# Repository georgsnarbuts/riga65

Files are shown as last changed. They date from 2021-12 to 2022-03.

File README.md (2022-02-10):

# riga65

<br />This work is licensed under a <a rel="license" href="http://creativecommons.org/licenses/by-nc/4.0/">Creative Commons Attribution-NonCommercial 4.0 International License</a>.  

a 65 % keyboard

A custom 65% mechanical keyboard with 100% through hole component assembly.  
Running atMega 32a MCU.  
Featuring a 128x32 oled display and an optional rotary encoder. Running QMK.    
  
Sample board built with gateron yellow switches (filmed and lubed with krytox 205 grade 0) and durock stabilizers.  

IMG_1587 2-min
  






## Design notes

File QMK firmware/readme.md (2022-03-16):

# riga65

*A short description of the keyboard/project*

* Keyboard Maintainer: [Georgs Narbuts](https://github.com/georgsnarbuts)
* Hardware Supported: Riga65 pcb, atmega32a mcu.

Make example for this keyboard (after setting up your build environment):

    make riga65:default

Flashing example for this keyboard:

    make riga65:default:flash

See the [build environment setup](https://docs.qmk.fm/#/getting_started_build_tools) and the [make instructions](https://docs.qmk.fm/#/getting_started_make_guide) for more information. Brand new to QMK? Start with our [Complete Newbs Guide](https://docs.qmk.fm/#/newbs).

## Bootloader

Enter the bootloader in 3 ways:

* **Bootmagic reset**: Hold down the key at (0,0) in the matrix (usually the top left key or Escape) and plug in the keyboard
* **Physical reset button**: Briefly press the button on the back of the PCB - some may have pads you must short instead
* **Keycode in layout**: Press the key mapped to `RESET` if it is available

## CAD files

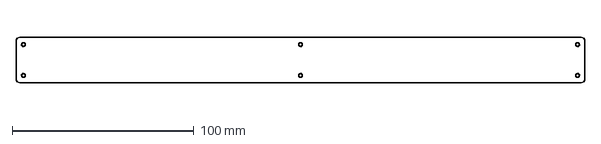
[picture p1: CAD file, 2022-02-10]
ACRYLIC GUARD/Untitled.dxf
313.0 x 25.0 mm

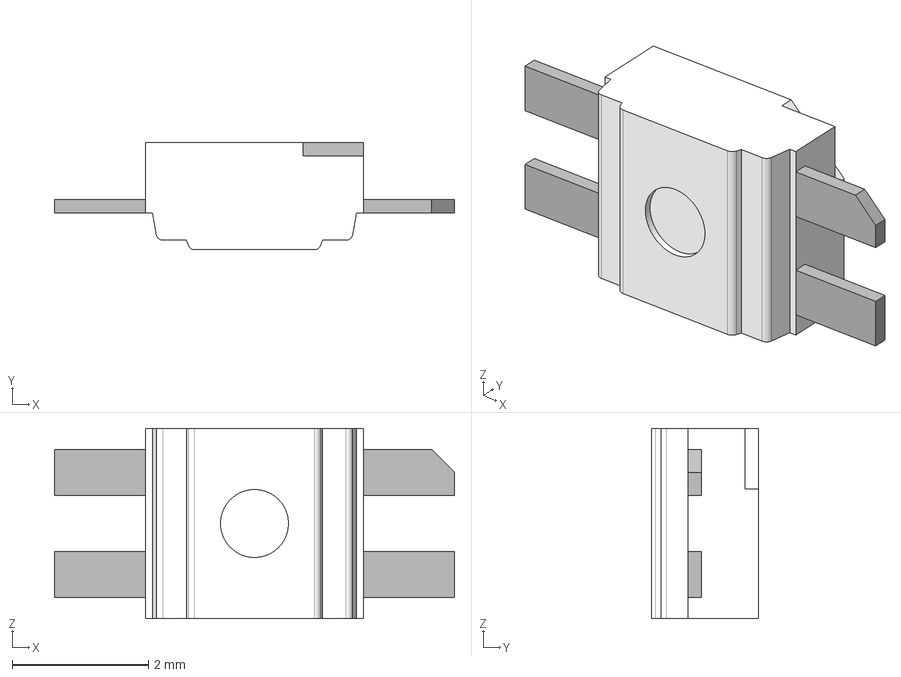
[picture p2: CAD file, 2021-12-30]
PCB/Keebio-Parts.pretty-master/3dmodels/SK6812MINI-E v1.step
5.88 x 1.58 x 2.80 mm

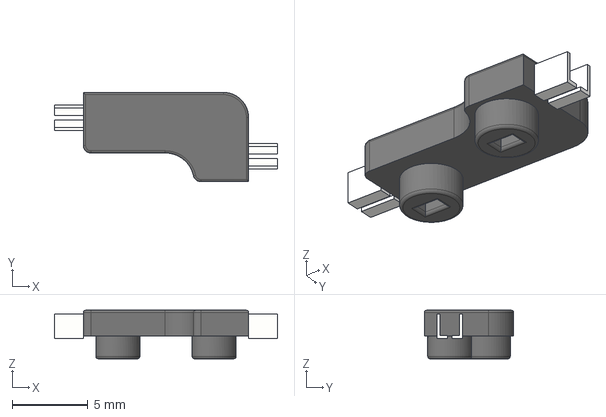
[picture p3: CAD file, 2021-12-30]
PCB/keyboard_parts.pretty-master/keyboard_parts.pretty-master/3D/Kailh_Socket.step
14.7 x 5.89 x 3.20 mm

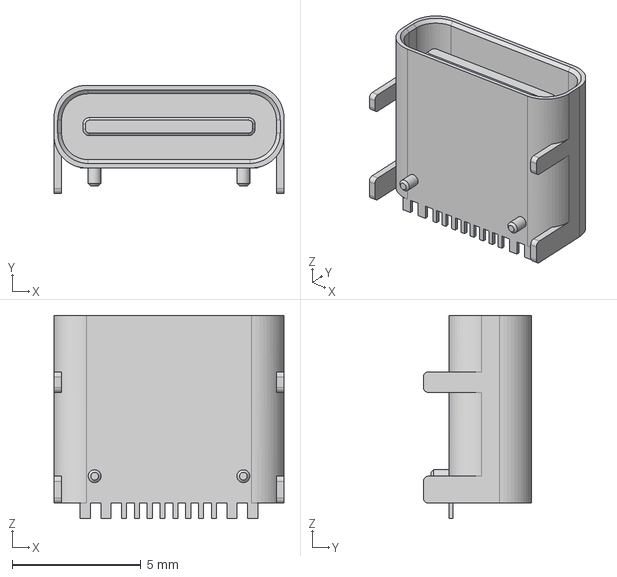
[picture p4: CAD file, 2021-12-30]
PCB/Keebio-Parts.pretty-master/3dmodels/HRO TYPE-C-31-M-12.step
8.94 x 4.21 x 7.90 mm

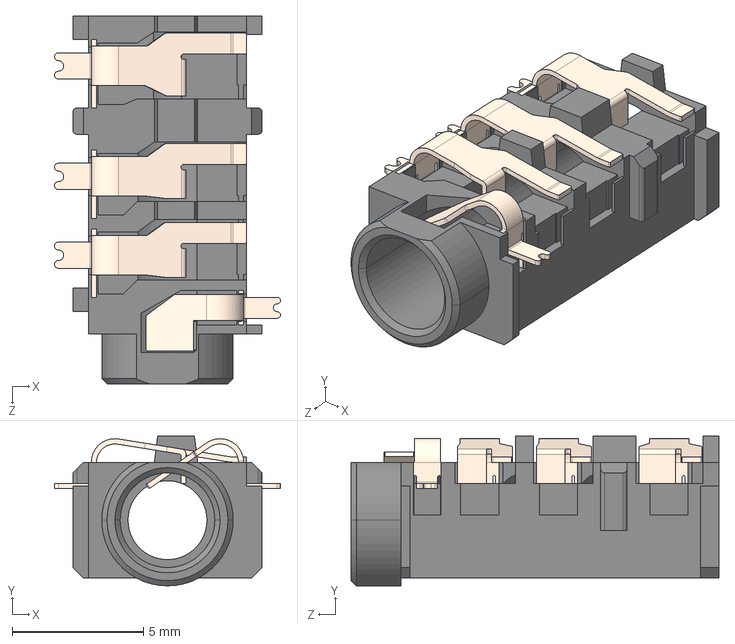
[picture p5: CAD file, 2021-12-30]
PCB/Keebio-Parts.pretty-master/3dmodels/CUI_SJ-43614-SMT-TR.step
8.60 x 5.70 x 14.0 mm

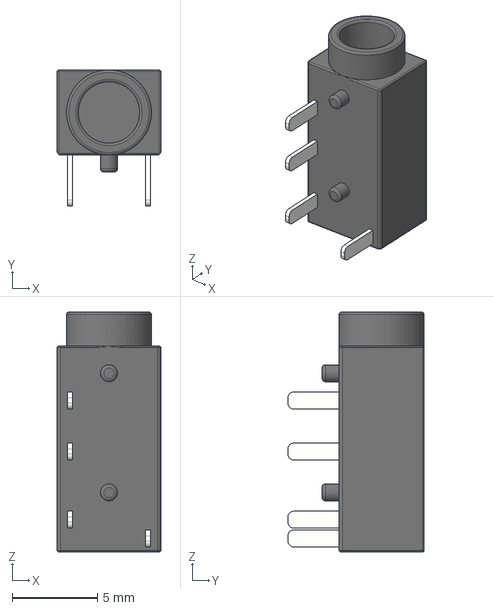
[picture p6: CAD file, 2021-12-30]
PCB/Keebio-Parts.pretty-master/3dmodels/PJ-320A.step
6.10 x 8.00 x 14.1 mm

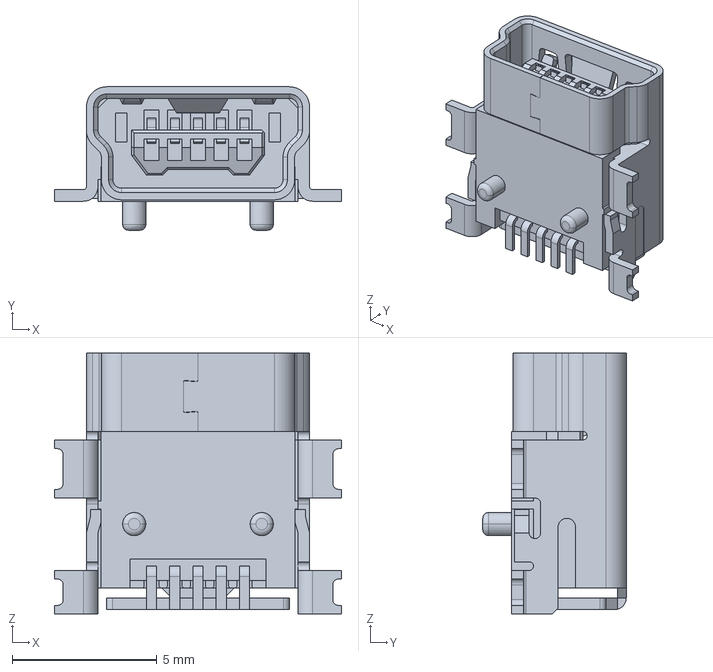
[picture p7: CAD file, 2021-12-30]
PCB/keyboard_parts.pretty-master/keyboard_parts.pretty-master/3D/675031020.stp
9.90 x 4.95 x 9.00 mm

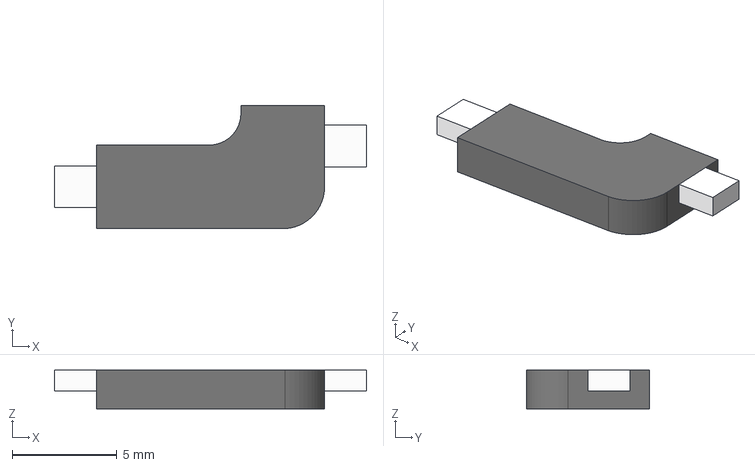
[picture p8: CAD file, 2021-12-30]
PCB/keyboard_parts.pretty-master/keyboard_parts.pretty-master/3D/PG151101S11.step
14.9 x 5.89 x 1.85 mm

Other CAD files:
PCB/keyboard_parts.pretty-master/keyboard_parts.pretty-master/PG151101S11.f3d

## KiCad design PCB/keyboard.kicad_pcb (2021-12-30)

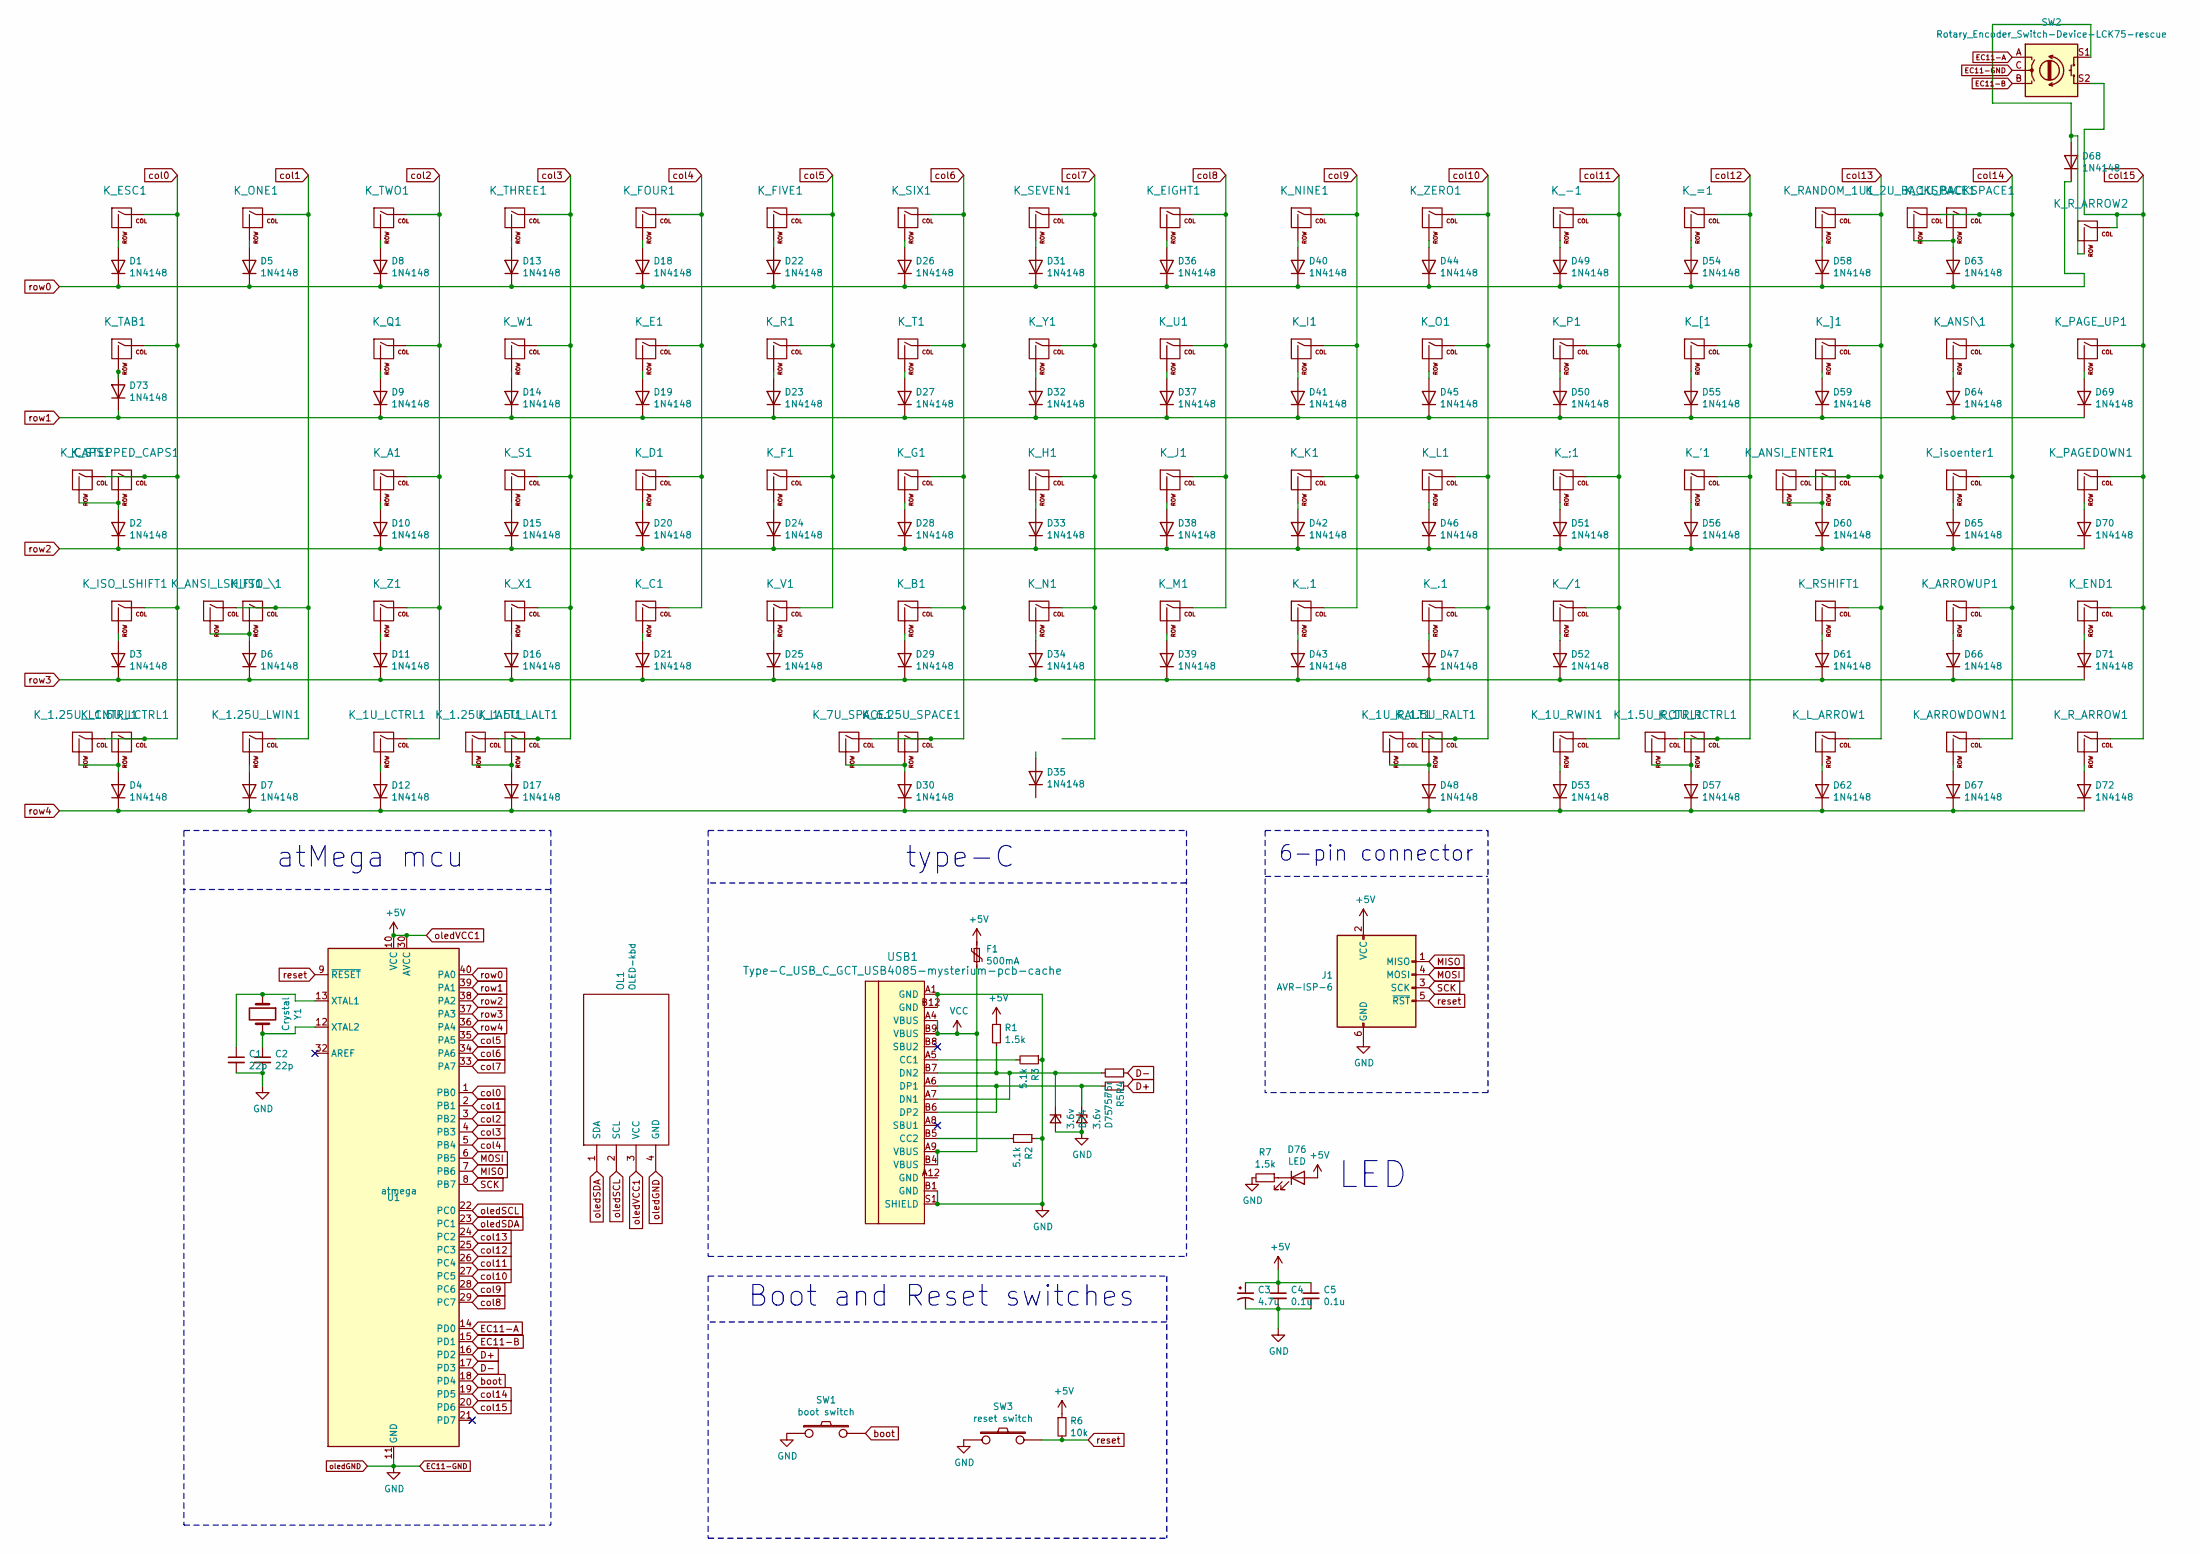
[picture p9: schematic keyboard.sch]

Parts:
C1, C2: 22p; C_Disc_D3.0mm_W1.6mm_P2.50mm
C3: 4.7u; CP_Radial_D4.0mm_P1.50mm
C4, C5: 0.1u; C_Disc_D4.3mm_W1.9mm_P5.00mm
D1, D2, D3, D4, D5, D6, D7, D8, D9, D10, D11, D12, D13, D14, D15, D16, D17, D18, D19, D20, D21, D22, D23, D24, D25, D26, D27, D28, D29, D30, D31, D32, D33, D34, D35, D36, D37, D38, D39, D40, D41, D42, D43, D44, D45, D46, D47, D48, D49, D50, D51, D52, D53, D54, D55, D56, D57, D58, D59, D60, D61, D62, D63, D64, D65, D66, D67, D68, D69, D70, D71, D72, D73: 1N4148; D_DO-35_SOD27_P5.08mm_Horizontal
D74, D75: 3.6v; D_DO-35_SOD27_P5.08mm_Horizontal
D76: LED; LED_D3.0mm
F1: 500mA; polyfuse_5.1mm
J1: AVR-ISP-6; AVR_ICSP_3x2
K_1.5U_LALT1, K_1.5U_LCTRL1, K_1.5U_RALT1, K_1.5U_RCTRL1: KEYSW; MXOnly-1.5U-NoLED
K_1.25U_LALT1, K_1.25U_LCNTRL1, K_1.25U_LWIN1: KEYSW; MXOnly-1.25U-NoLED
K_1U_BACKSPACE1, K_1U_LCTRL1, K_1U_RALT1, K_1U_RCTRL1, K_1U_RWIN1, K_.1: KEYSW; MXOnly-1U-NoLED
K_2U_BACKSPACE1: KEYSW; MXOnly-2U-NoLED
K_6.25U_SPACE1: KEYSW; MXOnly-6.25U-NoLED
K_7U_SPACE1: KEYSW; MXOnly-7U-NoLED
K_'1: KEYSW; MXOnly-1U-NoLED
K_,1: KEYSW; MXOnly-1U-NoLED
K_-1: KEYSW; MXOnly-1U-NoLED
K_/1: KEYSW; MXOnly-1U-NoLED
K_;1: KEYSW; MXOnly-1U-NoLED
K_=1: KEYSW; MXOnly-1U-NoLED
K_A1: KEYSW; MXOnly-1U-NoLED
K_ANSI\1: KEYSW; MXOnly-1.5U-NoLED
K_ANSI_ENTER1: KEYSW; MXOnly-2.25U-NoLED
K_ANSI_LSHIFT1: KEYSW; MXOnly-2.25U-NoLED
K_ARROWDOWN1: KEYSW; MXOnly-1U-NoLED
K_ARROWUP1: KEYSW; MXOnly-1U-NoLED
K_B1: KEYSW; MXOnly-1U-NoLED
K_C1: KEYSW; MXOnly-1U-NoLED
K_CAPS1: KEYSW; MXOnly-1.75U-NoLED
K_D1: KEYSW; MXOnly-1U-NoLED
K_E1: KEYSW; MXOnly-1U-NoLED
K_EIGHT1: KEYSW; MXOnly-1U-NoLED
K_END1: KEYSW; MXOnly-1U-NoLED
K_ESC1: KEYSW; MXOnly-1U-NoLED
K_F1: KEYSW; MXOnly-1U-NoLED
K_FIVE1: KEYSW; MXOnly-1U-NoLED
K_FOUR1: KEYSW; MXOnly-1U-NoLED
K_G1: KEYSW; MXOnly-1U-NoLED
K_H1: KEYSW; MXOnly-1U-NoLED
K_I1: KEYSW; MXOnly-1U-NoLED
K_ISO_LSHIFT1: KEYSW; MXOnly-1.25U-NoLED
K_ISO_\1: KEYSW; MXOnly-1U-NoLED
K_J1: KEYSW; MXOnly-1U-NoLED
K_K1: KEYSW; MXOnly-1U-NoLED
K_L1: KEYSW; MXOnly-1U-NoLED
K_L_ARROW1: KEYSW; MXOnly-1U-NoLED
K_M1: KEYSW; MXOnly-1U-NoLED
K_N1: KEYSW; MXOnly-1U-NoLED
K_NINE1: KEYSW; MXOnly-1U-NoLED
K_O1: KEYSW; MXOnly-1U-NoLED
K_ONE1: KEYSW; MXOnly-1U-NoLED
K_P1: KEYSW; MXOnly-1U-NoLED
K_PAGEDOWN1: KEYSW; MXOnly-1U-NoLED
K_PAGE_UP1: KEYSW; MXOnly-1U-NoLED
K_Q1: KEYSW; MXOnly-1U-NoLED
K_R1: KEYSW; MXOnly-1U-NoLED
K_RANDOM_1U1: KEYSW; MXOnly-1U-NoLED
K_RSHIFT1: KEYSW; MXOnly-1.75U-NoLED
K_R_ARROW1, K_R_ARROW2: KEYSW; MXOnly-1U-NoLED
K_S1: KEYSW; MXOnly-1U-NoLED
K_SEVEN1: KEYSW; MXOnly-1U-NoLED
K_SIX1: KEYSW; MXOnly-1U-NoLED
K_STEPPED_CAPS1: KEYSW; MXOnly-1.25U-NoLED
K_T1: KEYSW; MXOnly-1U-NoLED
K_TAB1: KEYSW; MXOnly-1.5U-NoLED
K_THREE1: KEYSW; MXOnly-1U-NoLED
K_TWO1: KEYSW; MXOnly-1U-NoLED
K_U1: KEYSW; MXOnly-1U-NoLED
K_V1: KEYSW; MXOnly-1U-NoLED
K_W1: KEYSW; MXOnly-1U-NoLED
K_X1: KEYSW; MXOnly-1U-NoLED
K_Y1: KEYSW; MXOnly-1U-NoLED
K_Z1: KEYSW; MXOnly-1U-NoLED
K_ZERO1: KEYSW; MXOnly-1U-NoLED
K_[1: KEYSW; MXOnly-1U-NoLED
K_]1: KEYSW; MXOnly-1U-NoLED
K_isoenter1: KEYSW; MXOnly-ISO-ReversedStabilizers
OL1: OLED-kbd; ssd1306 128x32 oled
R1, R7: 1.5k; R_Axial_DIN0204_L3.6mm_D1.6mm_P7.62mm_Horizontal
R2, R3: 5.1k; R_Axial_DIN0204_L3.6mm_D1.6mm_P7.62mm_Horizontal
R4, R5: 75r; R_Axial_DIN0204_L3.6mm_D1.6mm_P7.62mm_Horizontal
R6: 10k; R_Axial_DIN0204_L3.6mm_D1.6mm_P7.62mm_Horizontal
SW1: boot switch; SW_PUSH_6mm
SW2: Rotary_Encoder_Switch-Device-LCK75-rescue; RotaryEncoder_Alps_EC11E-Switch_Vertical_H20mm
SW3: reset switch; SW_PUSH_6mm
U1: atmega; DIP-40_W15.24mm
USB1: Type-C_USB_C_GCT_USB4085-mysterium-pcb-cache; USB_C_GCT_USB4085
Y1: Crystal; Crystal_HC49-4H_Vertical
`1: KEYSW; MXOnly-1U-NoLED

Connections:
D+: R5.1, U1.16 (PD2)
D-: R4.1, U1.17 (PD3)
EC11-A: SW2.A, U1.14 (PD0)
EC11-B: SW2.B, U1.15 (PD1)
EC11-GND: C1.2, C2.2, C3.2, C4.2, C5.2, D74.2 (A), D75.2 (A), J1.6 (GND), OL1.4 (GND), R2.1, R3.1, R7.2, SW1.1, SW2.C, SW3.1, U1.11 (GND), U1.31 (GND), USB1.A1 (GND), USB1.B1 (GND), USB1.B12 (GND), USB1.S1 (SHIELD)
MISO: J1.1 (MISO), U1.7 (PB6)
MOSI: J1.4 (MOSI), U1.6 (PB5)
unnamed: C1.1, U1.13 (XTAL1), Y1.1
unnamed: C2.1, U1.12 (XTAL2), Y1.2
unnamed: D1.2 (A), K_ESC1.2 (ROW)
unnamed: D2.2 (A), K_CAPS1.2 (ROW), K_STEPPED_CAPS1.2 (ROW)
unnamed: D3.2 (A), K_ISO_LSHIFT1.2 (ROW)
unnamed: D4.2 (A), K_1.5U_LCTRL1.2 (ROW), K_1.25U_LCNTRL1.2 (ROW)
unnamed: D5.2 (A), K_ONE1.2 (ROW)
unnamed: D6.2 (A), K_ANSI_LSHIFT1.2 (ROW), K_ISO_\1.2 (ROW)
unnamed: D7.2 (A), K_1.25U_LWIN1.2 (ROW)
unnamed: D8.2 (A), K_TWO1.2 (ROW)
unnamed: D9.2 (A), K_Q1.2 (ROW)
unnamed: D10.2 (A), K_A1.2 (ROW)
unnamed: D11.2 (A), K_Z1.2 (ROW)
unnamed: D12.2 (A), K_1U_LCTRL1.2 (ROW)
unnamed: D13.2 (A), K_THREE1.2 (ROW)
unnamed: D14.2 (A), K_W1.2 (ROW)
unnamed: D15.2 (A), K_S1.2 (ROW)
unnamed: D16.2 (A), K_X1.2 (ROW)
unnamed: D17.2 (A), K_1.5U_LALT1.2 (ROW), K_1.25U_LALT1.2 (ROW)
unnamed: D18.2 (A), K_FOUR1.2 (ROW)
unnamed: D19.2 (A), K_E1.2 (ROW)
unnamed: D20.2 (A), K_D1.2 (ROW)
unnamed: D21.2 (A), K_C1.2 (ROW)
unnamed: D22.2 (A), K_FIVE1.2 (ROW)
unnamed: D23.2 (A), K_R1.2 (ROW)
unnamed: D24.2 (A), K_F1.2 (ROW)
unnamed: D25.2 (A), K_V1.2 (ROW)
unnamed: D26.2 (A), K_SIX1.2 (ROW)
unnamed: D27.2 (A), K_T1.2 (ROW)
unnamed: D28.2 (A), K_G1.2 (ROW)
unnamed: D29.2 (A), K_B1.2 (ROW)
unnamed: D30.2 (A), K_6.25U_SPACE1.2 (ROW), K_7U_SPACE1.2 (ROW)
unnamed: D31.2 (A), K_SEVEN1.2 (ROW)
unnamed: D32.2 (A), K_Y1.2 (ROW)
unnamed: D33.2 (A), K_H1.2 (ROW)
unnamed: D34.2 (A), K_N1.2 (ROW)
unnamed: D36.2 (A), K_EIGHT1.2 (ROW)
unnamed: D37.2 (A), K_U1.2 (ROW)
unnamed: D38.2 (A), K_J1.2 (ROW)
unnamed: D39.2 (A), K_M1.2 (ROW)
unnamed: D40.2 (A), K_NINE1.2 (ROW)
unnamed: D41.2 (A), K_I1.2 (ROW)
unnamed: D42.2 (A), K_K1.2 (ROW)
unnamed: D43.2 (A), K_,1.2 (ROW)
unnamed: D44.2 (A), K_ZERO1.2 (ROW)
unnamed: D45.2 (A), K_O1.2 (ROW)
unnamed: D46.2 (A), K_L1.2 (ROW)
unnamed: D47.2 (A), K_.1.2 (ROW)
unnamed: D48.2 (A), K_1.5U_RALT1.2 (ROW), K_1U_RALT1.2 (ROW)
unnamed: D49.2 (A), K_-1.2 (ROW)
unnamed: D50.2 (A), K_P1.2 (ROW)
unnamed: D51.2 (A), K_;1.2 (ROW)
unnamed: D52.2 (A), K_/1.2 (ROW)
unnamed: D53.2 (A), K_1U_RWIN1.2 (ROW)
unnamed: D54.2 (A), K_=1.2 (ROW)
unnamed: D55.2 (A), K_[1.2 (ROW)
unnamed: D56.2 (A), K_'1.2 (ROW)
unnamed: D57.2 (A), K_1.5U_RCTRL1.2 (ROW), K_1U_RCTRL1.2 (ROW)
unnamed: D58.2 (A), K_RANDOM_1U1.2 (ROW)
unnamed: D59.2 (A), K_]1.2 (ROW)
unnamed: D60.2 (A), K_ANSI_ENTER1.2 (ROW), `1.2 (ROW)
unnamed: D61.2 (A), K_RSHIFT1.2 (ROW)
unnamed: D62.2 (A), K_L_ARROW1.2 (ROW)
unnamed: D63.2 (A), K_1U_BACKSPACE1.2 (ROW), K_2U_BACKSPACE1.2 (ROW)
unnamed: D64.2 (A), K_ANSI\1.2 (ROW)
unnamed: D65.2 (A), K_isoenter1.2 (ROW)
unnamed: D66.2 (A), K_ARROWUP1.2 (ROW)
unnamed: D67.2 (A), K_ARROWDOWN1.2 (ROW)
unnamed: D68.2 (A), K_R_ARROW2.2 (ROW), SW2.S1
unnamed: D69.2 (A), K_PAGE_UP1.2 (ROW)
unnamed: D70.2 (A), K_PAGEDOWN1.2 (ROW)
unnamed: D71.2 (A), K_END1.2 (ROW)
unnamed: D72.2 (A), K_R_ARROW1.2 (ROW)
unnamed: D73.2 (A), K_TAB1.2 (ROW)
unnamed: D74.1 (K), R1.2, R4.2, USB1.A7 (DN1), USB1.B7 (DN2)
unnamed: D75.1 (K), R5.2, USB1.A6 (DP1), USB1.B6 (DP2)
unnamed: D76.1 (K), R7.1
unnamed: R2.2, USB1.B5 (CC2)
unnamed: R3.2, USB1.A5 (CC1)
SCK: J1.3 (SCK), U1.8 (PB7)
VCC: F1.2, USB1.A4 (VBUS), USB1.A9 (VBUS), USB1.B4 (VBUS), USB1.B9 (VBUS)
boot: SW1.2, U1.18 (PD4)
col0: K_1.5U_LCTRL1.1 (COL), K_1.25U_LCNTRL1.1 (COL), K_CAPS1.1 (COL), K_ESC1.1 (COL), K_ISO_LSHIFT1.1 (COL), K_STEPPED_CAPS1.1 (COL), K_TAB1.1 (COL), U1.1 (PB0)
col1: K_1.25U_LWIN1.1 (COL), K_ANSI_LSHIFT1.1 (COL), K_ISO_\1.1 (COL), K_ONE1.1 (COL), U1.2 (PB1)
col2: K_1U_LCTRL1.1 (COL), K_A1.1 (COL), K_Q1.1 (COL), K_TWO1.1 (COL), K_Z1.1 (COL), U1.3 (PB2)
col3: K_1.5U_LALT1.1 (COL), K_1.25U_LALT1.1 (COL), K_S1.1 (COL), K_THREE1.1 (COL), K_W1.1 (COL), K_X1.1 (COL), U1.4 (PB3)
col4: K_C1.1 (COL), K_D1.1 (COL), K_E1.1 (COL), K_FOUR1.1 (COL), U1.5 (PB4)
col5: K_F1.1 (COL), K_FIVE1.1 (COL), K_R1.1 (COL), K_V1.1 (COL), U1.35 (PA5)
col6: K_6.25U_SPACE1.1 (COL), K_7U_SPACE1.1 (COL), K_B1.1 (COL), K_G1.1 (COL), K_SIX1.1 (COL), K_T1.1 (COL), U1.34 (PA6)
col7: K_H1.1 (COL), K_N1.1 (COL), K_SEVEN1.1 (COL), K_Y1.1 (COL), U1.33 (PA7)
col8: K_EIGHT1.1 (COL), K_J1.1 (COL), K_M1.1 (COL), K_U1.1 (COL), U1.29 (PC7)
col9: K_,1.1 (COL), K_I1.1 (COL), K_K1.1 (COL), K_NINE1.1 (COL), U1.28 (PC6)
col10: K_1.5U_RALT1.1 (COL), K_1U_RALT1.1 (COL), K_.1.1 (COL), K_L1.1 (COL), K_O1.1 (COL), K_ZERO1.1 (COL), U1.27 (PC5)
col11: K_1U_RWIN1.1 (COL), K_-1.1 (COL), K_/1.1 (COL), K_;1.1 (COL), K_P1.1 (COL), U1.26 (PC4)
col12: K_1.5U_RCTRL1.1 (COL), K_1U_RCTRL1.1 (COL), K_'1.1 (COL), K_=1.1 (COL), K_[1.1 (COL), U1.25 (PC3)
col13: K_ANSI_ENTER1.1 (COL), K_L_ARROW1.1 (COL), K_RANDOM_1U1.1 (COL), K_RSHIFT1.1 (COL), K_]1.1 (COL), U1.24 (PC2), `1.1 (COL)
col14: K_1U_BACKSPACE1.1 (COL), K_2U_BACKSPACE1.1 (COL), K_ANSI\1.1 (COL), K_ARROWDOWN1.1 (COL), K_ARROWUP1.1 (COL), K_isoenter1.1 (COL), U1.19 (PD5)
col15: K_END1.1 (COL), K_PAGEDOWN1.1 (COL), K_PAGE_UP1.1 (COL), K_R_ARROW1.1 (COL), K_R_ARROW2.1 (COL), SW2.S2, U1.20 (PD6)
oledSCL: OL1.2 (SCL), U1.22 (PC0)
oledSDA: OL1.1 (SDA), U1.23 (PC1)
oledVCC1: C3.1, C4.1, C5.1, D76.2 (A), F1.1, J1.2 (VCC), OL1.3 (VCC), R1.1, R6.1, U1.10 (VCC), U1.30 (AVCC)
reset: J1.5 (~RST), R6.2, SW3.2, U1.9 (~RESET)
row0: D1.1 (K), D5.1 (K), D8.1 (K), D13.1 (K), D18.1 (K), D22.1 (K), D26.1 (K), D31.1 (K), D36.1 (K), D40.1 (K), D44.1 (K), D49.1 (K), D54.1 (K), D58.1 (K), D63.1 (K), D68.1 (K), U1.40 (PA0)
row1: D9.1 (K), D14.1 (K), D19.1 (K), D23.1 (K), D27.1 (K), D32.1 (K), D37.1 (K), D41.1 (K), D45.1 (K), D50.1 (K), D55.1 (K), D59.1 (K), D64.1 (K), D69.1 (K), D73.1 (K), U1.39 (PA1)
row2: D2.1 (K), D10.1 (K), D15.1 (K), D20.1 (K), D24.1 (K), D28.1 (K), D33.1 (K), D38.1 (K), D42.1 (K), D46.1 (K), D51.1 (K), D56.1 (K), D60.1 (K), D65.1 (K), D70.1 (K), U1.38 (PA2)
row3: D3.1 (K), D6.1 (K), D11.1 (K), D16.1 (K), D21.1 (K), D25.1 (K), D29.1 (K), D34.1 (K), D39.1 (K), D43.1 (K), D47.1 (K), D52.1 (K), D61.1 (K), D66.1 (K), D71.1 (K), U1.37 (PA3)
row4: D4.1 (K), D7.1 (K), D12.1 (K), D17.1 (K), D30.1 (K), D48.1 (K), D53.1 (K), D57.1 (K), D62.1 (K), D67.1 (K), D72.1 (K), U1.36 (PA4)

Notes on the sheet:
Boot and Reset switches
6-pin connector
type-C
atMega mcu
LED

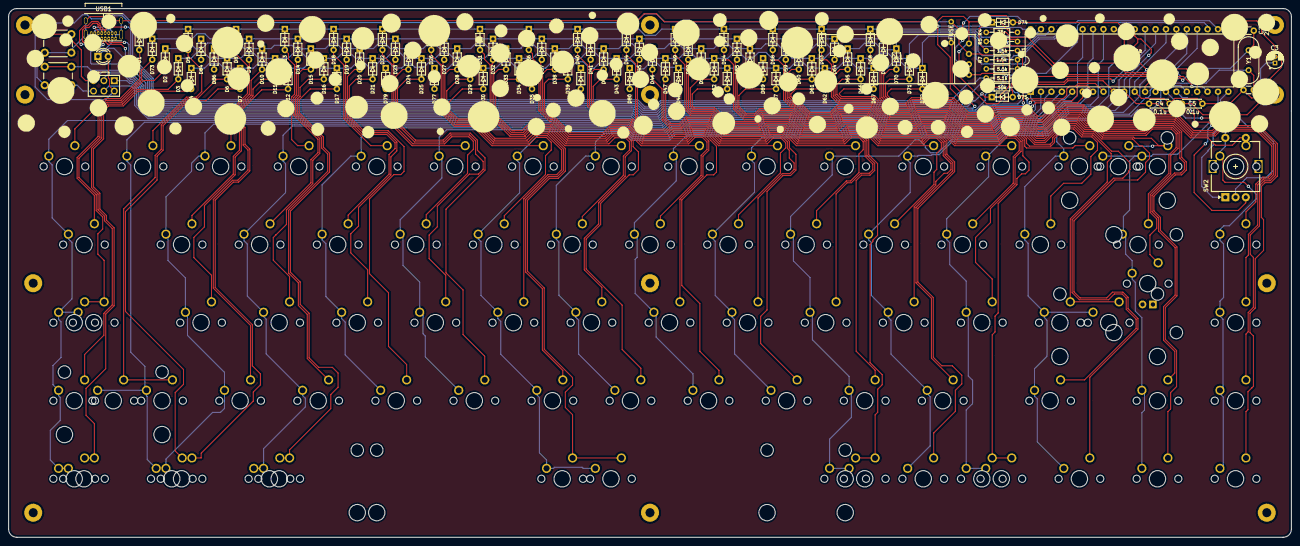
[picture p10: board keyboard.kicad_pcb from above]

Board: 2 copper layers, 313.0 x 129.0 mm, 185 parts (0 on the bottom side), 114 nets.

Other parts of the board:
D77, D79, D80, D81, D84, D86, D89: 1N4148; D_DO-35_SOD27_P5.08mm_Horizontal

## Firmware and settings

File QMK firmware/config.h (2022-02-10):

// Copyright 2021 Georgs Narbuts (@georgsnarbuts)
// SPDX-License-Identifier: GPL-2.0-or-later

#pragma once

#include "config_common.h"

/* USB Device descriptor parameter */
#define VENDOR_ID    0x0953
#define PRODUCT_ID   0x1603
#define DEVICE_VER   0x0100
#define MANUFACTURER georgsnarbuts
#define PRODUCT      riga65






/* key matrix size */
#define MATRIX_ROWS 5
#define MATRIX_COLS 16
#define MATRIX_ROW_PINS { A0, A1, A2, A3, A4}
#define MATRIX_COL_PINS { B0, B1, B2, B3, B4, A5, A6, A7, C7, C6, C5, C4, C3, C2, D5, D6}

/*
 * Keyboard Matrix Assignments
 *
 * Change this to how you wired your keyboard
 * COLS: AVR pins used for columns, left to right
 * ROWS: AVR pins used for rows, top to bottom
 * DIODE_DIRECTION: COL2ROW = COL = Anode (+), ROW = Cathode (-, marked on diode)
 *                  ROW2COL = ROW = Anode (+), COL = Cathode (-, marked on diode)
 *
 */

/* encoder pins */
#define ENCODERS_PAD_A { D0 }
#define ENCODERS_PAD_B { D1 }

/* encoder resolution */
#define ENCODER_RESOLUTION 4
#define TAP_CODE_DELAY 10

/* COL2ROW or ROW2COL */
#define DIODE_DIRECTION COL2ROW

/* Set 0 if debouncing isn't needed */
#define DEBOUNCE 5

/*
 * Split Keyboard specific options, make sure you have 'SPLIT_KEYBOARD = yes' in your rules.mk, and define SOFT_SERIAL_PIN.
 */
//#define SOFT_SERIAL_PIN D0  // or D1, D2, D3, E6

//#define LED_NUM_LOCK_PIN B0
//#define LED_CAPS_LOCK_PIN B1
//#define LED_SCROLL_LOCK_PIN B2
//#define LED_COMPOSE_PIN B3
//#define LED_KANA_PIN B4

//#define BACKLIGHT_PIN B7
//#define BACKLIGHT_LEVELS 3
//#define BACKLIGHT_BREATHING

//#define RGB_DI_PIN E2
//#ifdef RGB_DI_PIN
//#    define RGBLED_NUM 16
//#    define RGBLIGHT_HUE_STEP 8
//#    define RGBLIGHT_SAT_STEP 8
//#    define RGBLIGHT_VAL_STEP 8
//#    define RGBLIGHT_LIMIT_VAL 255 /* The maximum brightness level */
//#    define RGBLIGHT_SLEEP  /* If defined, the RGB lighting will be switched off when the host goes to sleep */
/*== all animations enable ==*/
//#    define RGBLIGHT_ANIMATIONS
/*== or choose animations ==*/
//#    define RGBLIGHT_EFFECT_BREATHING
//#    define RGBLIGHT_EFFECT_RAINBOW_MOOD
//#    define RGBLIGHT_EFFECT_RAINBOW_SWIRL
//#    define RGBLIGHT_EFFECT_SNAKE
//#    define RGBLIGHT_EFFECT_KNIGHT
//#    define RGBLIGHT_EFFECT_CHRISTMAS
//#    define RGBLIGHT_EFFECT_STATIC_GRADIENT
//#    define RGBLIGHT_EFFECT_RGB_TEST
//#    define RGBLIGHT_EFFECT_ALTERNATING
/*== customize breathing effect ==*/
/*==== (DEFAULT) use fixed table instead of exp() and sin() ====*/
//#    define RGBLIGHT_BREATHE_TABLE_SIZE 256      // 256(default) or 128 or 64
/*==== use exp() and sin() ====*/
//#    define RGBLIGHT_EFFECT_BREATHE_CENTER 1.85  // 1 to 2.7
//#    define RGBLIGHT_EFFECT_BREATHE_MAX    255   // 0 to 255
//#endif

/* Debounce reduces chatter (unintended double-presses) - set 0 if debouncing is not needed */
#define DEBOUNCE 5

/* define if matrix has ghost (lacks anti-ghosting diodes) */
//#define MATRIX_HAS_GHOST

/* Mechanical locking support. Use KC_LCAP, KC_LNUM or KC_LSCR instead in keymap */
#define LOCKING_SUPPORT_ENABLE
/* Locking resynchronize hack */
#define LOCKING_RESYNC_ENABLE

/* If defined, GRAVE_ESC will always act as ESC when CTRL is held.
 * This is useful for the Windows task manager shortcut (ctrl+shift+esc).
 */
//#define GRAVE_ESC_CTRL_OVERRIDE

/*
 * Force NKRO
 *
 * Force NKRO (nKey Rollover) to be enabled by default, regardless of the saved
 * state in the bootmagic EEPROM settings. (Note that NKRO must be enabled in the
 * makefile for this to work.)
 *
 * If forced on, NKRO can be disabled via magic key (default = LShift+RShift+N)
 * until the next keyboard reset.
 *
 * NKRO may prevent your keystrokes from being detected in the BIOS, but it is
 * fully operational during normal computer usage.
 *
 * For a less heavy-handed approach, enable NKRO via magic key (LShift+RShift+N)
 * or via bootmagic (hold SPACE+N while plugging in the keyboard). Once set by
 * bootmagic, NKRO mode will always be enabled until it is toggled again during a
 * power-up.
 *
 */
//#define FORCE_NKRO

/*
 * Feature disable options
 *  These options are also useful to firmware size reduction.
 */

/* disable debug print */
//#define NO_DEBUG

/* disable print */
//#define NO_PRINT

/* disable action features */
//#define NO_ACTION_LAYER
//#define NO_ACTION_TAPPING
//#define NO_ACTION_ONESHOT

/* disable these deprecated features by default */
#define NO_ACTION_MACRO
#define NO_ACTION_FUNCTION

/* Bootmagic Lite key configuration */
//#define BOOTMAGIC_LITE_ROW 0
//#define BOOTMAGIC_LITE_COLUMN 0

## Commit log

2021-12-30 kicad files
    [675031020.stp, CUI_SJ-43614-SMT-TR.step, HRO TYPE-C-31-M-12.step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]
2022-02-10 better organisation
    reorganised for better readability
    [675031020.stp, CUI_SJ-43614-SMT-TR.step, HRO TYPE-C-31-M-12.step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]
